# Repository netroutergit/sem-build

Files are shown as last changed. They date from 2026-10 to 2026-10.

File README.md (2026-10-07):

# Homebuilt scanning electron microscope

A hobby project to design and build a working scanning electron microscope
(SEM) from scratch: vacuum system, electron gun, magnetic lenses, scan
electronics and imaging software.

This site is the friendly overview: what it is, how far along it is, a 3D
model to look at, and photos of the parts as they get made. The detailed
engineering notes live in a separate private repo.

Site: https://netroutergit.github.io/sem-build/

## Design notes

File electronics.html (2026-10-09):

Homebuilt SEM

# Electronics

How the electronics are split up, what talks to what, and the one circuit that is allowed to switch on the high voltage. Nothing on this page has been built yet.

This page is a snapshot of the current design, not a history. The design will change many times before a board is ordered. When it does, the diagrams here are replaced and the reasons rewritten. Last revised October 2026.

## Three layers

Everything electronic in the instrument sits in one of three layers, chosen by how fast it has to react.

- The scan engine, an FPGA. An FPGA is a chip whose logic is wired up by the designer rather than fixed at the factory, so it does many things at once with exact timing. It steps the beam across the sample and samples the detector once per pixel, a million times a second, and streams the frame to the PC.
- The machine controller, a microcontroller. Everything slow: pumping down, reading the gauge, setting lens currents, lighting the status display. Ordinary firmware.
- The interlock chain, relays only. No firmware at all. It is the only thing that can permit the high voltage and the filament. The FPGA and the microcontroller can ask for high voltage off at any time, but neither can force it on.

## The boxes and the cables

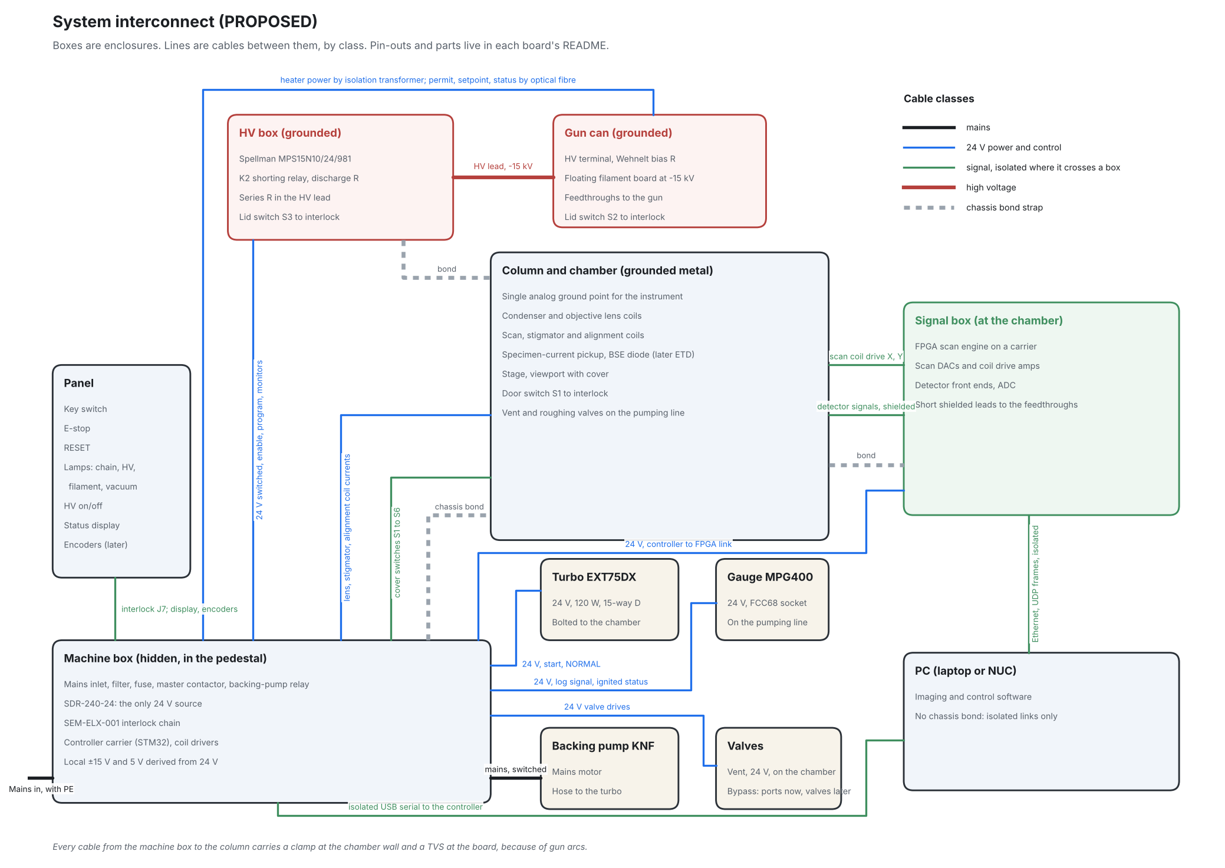
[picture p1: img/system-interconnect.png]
System interconnect diagram: a hidden machine box in the pedestal, a front panel, a grounded high-voltage box, a grounded gun can, the column and chamber, a signal box at the chamber, and the PC, wi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


Boxes are enclosures. Lines are cables, coloured by what they carry: mains, 24 volt power and control, isolated signals, high voltage, and chassis bonding straps. Pin-outs are deliberately left off.

- Machine box, hidden in the pedestal. Mains comes in through a filter and a master contactor. One industrial 24 volt supply feeds everything: turbo, gauge, valves, relays and the high-voltage module. Every other rail is made locally on the board that needs it. The interlock chain and the machine controller live here.
- Panel. A key switch, an emergency stop, a reset button, four lamps and a status display. The lamps are driven by relay contacts, not by software, so they tell the truth even if the controller is dead.
- High-voltage box and gun can. Both grounded metal. The 15 kV supply, its series resistor and the shorting relay are in the box. The gun's terminal and its floating filament supply are in the can on top of the column. Each has a lid switch in the interlock chain, because the air side of the gun is the one place 15 kV exists outside the vacuum.
- Column and chamber. Grounded metal and the single analog ground point of the instrument. The lens coils, scan coils and detectors are here, so the signal box sits right beside it with short shielded leads to the feedthroughs.
- Signal box, at the chamber. The FPGA on a carrier board, the scan drivers and the detector front ends. Fast, small signals stay close to where they are made.
- PC. No ground connection to the instrument at all. The FPGA streams frames over Ethernet, which is isolated by the transformers in every Ethernet port. The controller talks over a USB serial link through an isolator. Two cables, both floating, so a gun arc cannot find a path through the computer.

Every cable from the machine box to the column carries a clamp at the chamber wall and a protection device at the board, because an arc in the gun throws a fast pulse into anything connected to it.

## The interlock chain

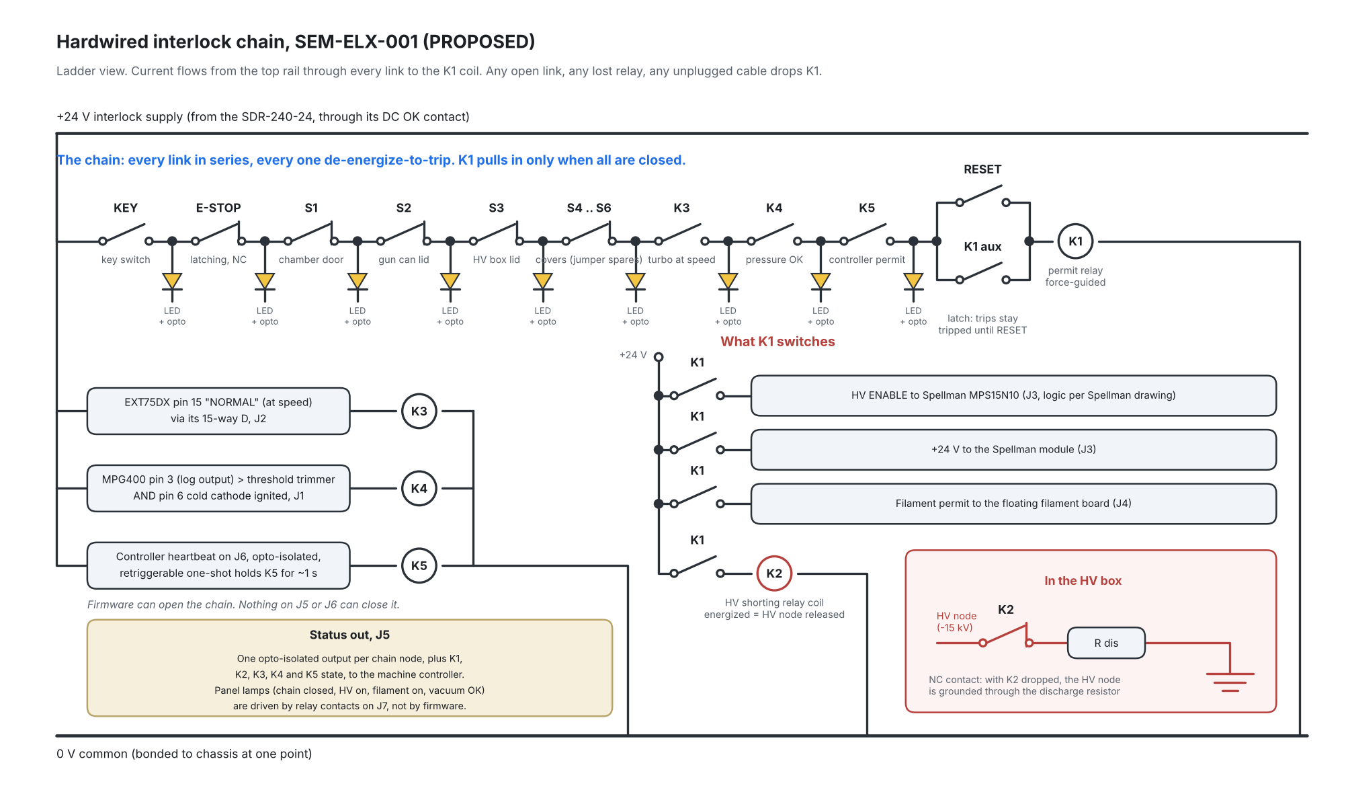
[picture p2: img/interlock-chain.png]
Ladder diagram of the interlock chain: key switch, emergency stop, cover switches, turbo-at-speed, pressure-OK and controller-permit contacts in series feeding the permit relay, with a latching rese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


Read it left to right along the top rail. Current has to pass through every switch and relay contact in series to reach the coil of the permit relay. Anything open, dropped or unplugged and the permit is gone.

- Everything is de-energize-to-trip. An open door, a dropped relay, an unplugged cable or a dead supply all look the same: the chain opens and high voltage goes off. There is no state in which a fault leaves the gun live.
- The links. A key switch. The emergency stop. A safety switch on the chamber door, the gun can lid, the high-voltage box lid and any further cover. A relay that only closes when the turbo reports it is at full speed. A relay that only closes when the gauge reads below the threshold and its cold cathode has actually lit, so an unlit gauge can never pass as vacuum. And a relay held in by the controller.
- The controller's permit is a heartbeat, not a level. The controller must toggle a line a few times a second. A one-shot keeps the relay in only while the toggling continues, so a crashed controller, a stuck pin or a pulled cable drops the high voltage within about a second. Nothing the controller can do closes any other link.
- It latches. After any trip the chain stays open until someone presses reset with every link closed. A door that closes again does not bring the gun back by itself.
- What the permit relay switches. The enable line and the 24 volt feed to the high-voltage module, so the module is unpowered when the chain is open regardless of the enable pin. The permit to the filament supply. And the coil of a shorting relay in the high-voltage box, whose normally closed contact grounds the high-voltage node through a discharge resistor whenever the chain is open or the relay loses power.
- Status can only go out. The controller gets an opto-isolated copy of every node for logging and the display, and the panel lamps are relay contacts. Neither path can close the chain.

The permit relay is a force-guided safety relay, the kind whose contacts are mechanically linked so that a welded contact shows up on the auxiliary contact instead of silently holding the gun live. The acceptance test for this board is simple: every input, opened in turn, must take the measured high voltage below 50 volts within one second.

## The boards

Six designs, about ten boards once the replicated ones are counted. One board outline and one connector family for all of them. The FPGA and microcontroller are bought modules on custom carriers rather than laid out from scratch.

Board | What it does
Interlock chain | The relay logic above. No firmware. The first board to be drawn.
Controller carrier | The microcontroller, its power, and the connectors to the gauge, turbo, valves and panel.
Scan and acquisition | Digital-to-analog converters for the scan coils, the detector analog-to-digital converter, and the FPGA carrier.
Coil driver, replicated | A precision current source. One per lens, stigmator and alignment coil, because a lens current that wanders by a part in ten thousand moves the focus.
Floating filament supply | Heats the filament while sitting at 15 kV below ground. See below.
Detector front end, replicated | A low-noise amplifier for the specimen current and the backscatter diode, later the photomultiplier electronics.

## Decisions, and the reasons behind them

- One 24 volt rail, everything else local. One supply to buy, one thing to fuse, and every board makes its own clean analog rails from it where they are used. There is no 12 volt rail because nothing needs one.
- Heating the filament across 15 kV with a transformer and light. The filament sits at the gun voltage, so its power has to cross a 15 kV barrier. The plan is a hand-wound transformer on a grounded ferrite ring: a 24 volt primary driven at high frequency, and a secondary of a few loose turns of 30 kV silicone wire whose insulation is the whole barrier. On the floating side a rectifier, a current regulator and a small microcontroller. The permit and setpoint come in over one plastic optical fibre and status goes back over another. No light, no filament. An earlier idea, a battery floating at gun voltage, was dropped: nothing to charge, nothing to run flat.
- Ethernet for the pictures, isolated serial for the controller. A frame is a megabyte and comes once a second, so Ethernet is the natural fit, and its port transformers give isolation for free. The controller has little to say and gets a slower link through a USB isolator. Both leave the PC ungrounded to the instrument.
- Relays for safety, not firmware. Firmware can have bugs, hang, or be mid-update. A relay chain fails only one way, open, and can be tested with a switch and a meter.
- Panel lamps from relay contacts. The lamp that says the chain is closed is wired to the chain. It cannot disagree with reality.
- Bought modules on custom carriers. Laying out a modern FPGA with its memory and power is a project in itself. A commercial module does that; the carrier only has to route its pins to the instrument's connectors.

The detailed engineering notes live in a separate private repository. This site is the friendly overview. Source for the site: github.com/netroutergit/sem-build.

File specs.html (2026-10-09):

Homebuilt SEM

# Headline numbers

These are design targets. Nothing has been measured yet; the first measurement will be the vacuum test. Each row says what the number means in plain words.

## The beam

What | Target | What it means
Beam energy | 5 to 15 kV | How hard the electrons are flung at the sample. Set by the voltage on the gun. Higher gives a finer spot but more X-rays, so 15 kV is the ceiling.
Electron source | Tungsten hairpin | A V-shaped tungsten wire heated to about 2,700 K. Electrons boil off the tip. The same kind of filament commercial SEMs used for decades, bought as a consumable.
Lenses | Two, magnetic | A condenser lens that does the first shrink of the beam, and an objective lens that forms the final focus on the sample. Both are coils in steel shells, made on the lathe.
Spot size, predicted | 130 to 255 nm | How small the beam can be focused with both lenses on. That is the detail the microscope can resolve. A human hair is about 70,000 nm across.
Spot size, first image | about 3 µm | With only the objective lens running. Coarser, but it carries over a hundred times more current, which makes the first image easy to get.
Beam current | 0.5 nA to over 100 nA | How many electrons per second land on the sample. A smaller spot always carries less current, so the best resolution comes with the weakest signal.

## The hardware

What | Target | What it means
Vacuum | 10⁻⁵ Torr | About one hundred-millionth of atmospheric pressure. Needed so electrons do not scatter off air, the filament does not burn out, and the high voltage does not arc. The pump bought should hold the chamber near 4 × 10⁻⁶ Torr, a little better than needed.
Turbo pump | Edwards EXT75DX, 61 L/s | A turbomolecular pump, a stack of blades spinning at tens of thousands of rpm, does the hard work. Bought used, drive electronics built in, 95 mm inlet flange. See milestone 2.
Backing pump | KNF dry diaphragm | Takes the chamber from atmosphere to about half a Torr and carries away the turbo's exhaust. No oil anywhere, so nothing can creep back toward the column.
Gauge | Inficon MPG400 | One gauge that reads from atmosphere down to a hundred-millionth of a Torr, by combining two sensors in one body and switching between them on its own.
Column height | about 450 mm | From the sample up to the top of the gun. The chamber and the pump hang below that.
Objective lens | 114 mm across, 95 mm tall | Three turned pieces of low-carbon steel around a 1,000-turn coil. The underside is tapered to a 24 mm nose so an X-ray detector can see the sample later.
Condenser lens | 110 mm across, 59 mm tall | Same construction, 1,500-turn coil. Both lenses fit a 12-inch lathe.
Sample chamber | 150 mm cube inside | Machined from aluminium with bolt-on, O-ring-sealed plates, so no welding and no leak detector needed.
Samples | up to about 25 mm | Sit on the standard half-inch pin stubs every SEM uses. Electrically conductive samples first, such as metal parts and meshes.
Scan | 1024 × 1024 pixels | At 1 microsecond per pixel, a full frame takes about a second. An FPGA steps the beam and samples the detector so every value lands in exactly the pixel it belongs to.

## The goals, in order

Goal | Passes when
First image | A copper mesh of known spacing is recognisable, and its measured spacing is within 10% of the real thing.
Real detector | A backscatter diode or a secondary-electron detector gives a cleaner picture than the simplest signal, and a two-metal sample shows which metal is which.
Sub-micron resolution | Detail under 1 µm resolved with both lenses running. Stretch goal: under 200 nm.
Automation | One-command pump-down, a motorised stage, autofocus, and stitched mosaics of many frames.
Element identification | An X-ray detector (EDS) that tells copper from aluminium by the energy of the X-rays each gives off. Budgeted and planned separately, but the chamber is designed so it fits.

The detailed engineering notes live in a separate private repository. This site is the friendly overview. Source for the site: github.com/netroutergit/sem-build.

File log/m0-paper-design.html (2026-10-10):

Homebuilt SEM

# Milestone 0: paper design

October 2026. Before buying anything, work the whole instrument through on paper so that a fundamental problem shows up while it is still free to fix.

## Why now

A home-built electron microscope has been an idea for years, and a slow gathering: metal stock, power supplies, interlock parts and gun sketches collected as they came along, none of it to a plan. What changed is not the physics. The skills the build needs, lathe and mill work, PCB design and software, had finally all come together in one workshop, so no part of it had to be farmed out or faked. And documentation, which would otherwise never have happened, became cheap: AI tools turn a session's working notes into a design record the same day, so every calculation, decision and surprise is written down while it is fresh. That record is what makes a milestone-gated plan possible, and it is why this milestone exists before a single part has been cut.

## What got done

- The optics close on paper. A simple model of the two-lens column predicts a spot of 130 to 255 nm with both lenses running, and about 3 µm with the objective alone. The sub-micron goal is realistic.
- The lenses were simulated and then drawn. A free finite-element program (FEMM) that calculates magnetic fields checked the steel shapes. It agrees with the simple model to within about 5%, and the steel stays comfortably below the point where it stops carrying more field. Both lenses now exist as 3D parts, three turned pieces each, and they fit the lathe. See the 3D model.
- The gun insulator was shaped by calculation. The same kind of field calculation, this time electric, found a shape for the high-voltage parts that stays within safe limits at 15 kV. The insulator will be machined from PEEK, a plastic that is easy to turn and holds off high voltage well.
- The whole column was laid out. Every dimension the physics depends on lives in one shared file, which the optics model, the field checks, the cross-section sketch and the CAD scripts all read. Change a number once and everything regenerates.
- The regulatory question was answered. Texas exempts electron microscopes from radiation-machine registration by name. The duty to keep X-rays below the limit stays, and the design treats that limit as a hard one.

## Surprises

- The gun could not be pumped. The first layout had the gun's vacuum pulled through the narrow beam tube. Working the numbers showed the tube passes far too little gas, and almost none once the tiny final aperture is fitted. The gun now gets its own hose to the chamber. Caught on paper before any hardware existed.
- The first gun shape would have arced. Two places broke the electric-field limit. The obvious fix, a rounded dome resting on the insulator, made it worse. A fat 25 mm stem standing clear of the surface fixed both.
- A flat lens blocks the X-ray view. The objective lens sits only 10 mm above the sample, and a future X-ray detector has to look at the sample from about 35 degrees. A flat-bottomed lens was in the way, so the underside now tapers to a 24 mm nose, as it does on commercial instruments.
- The condenser has a floor. With its chosen gap and bore it cannot focus shorter than about 4.4 mm, and that is what sets the resolution limit near 130 to 180 nm. Going further would need a smaller bore, a longer column or a third lens.

## Next

Measure the stray magnetic field in the workshop where the instrument will stand, since mains hum can push the beam around. Then the first real purchase: a used turbo pump, a backing pump and a gauge, proven on a test volume before anything custom is machined. That purchase has since been made; see milestone 2.

The detailed engineering notes live in a separate private repository. This site is the friendly overview. Source for the site: github.com/netroutergit/sem-build.

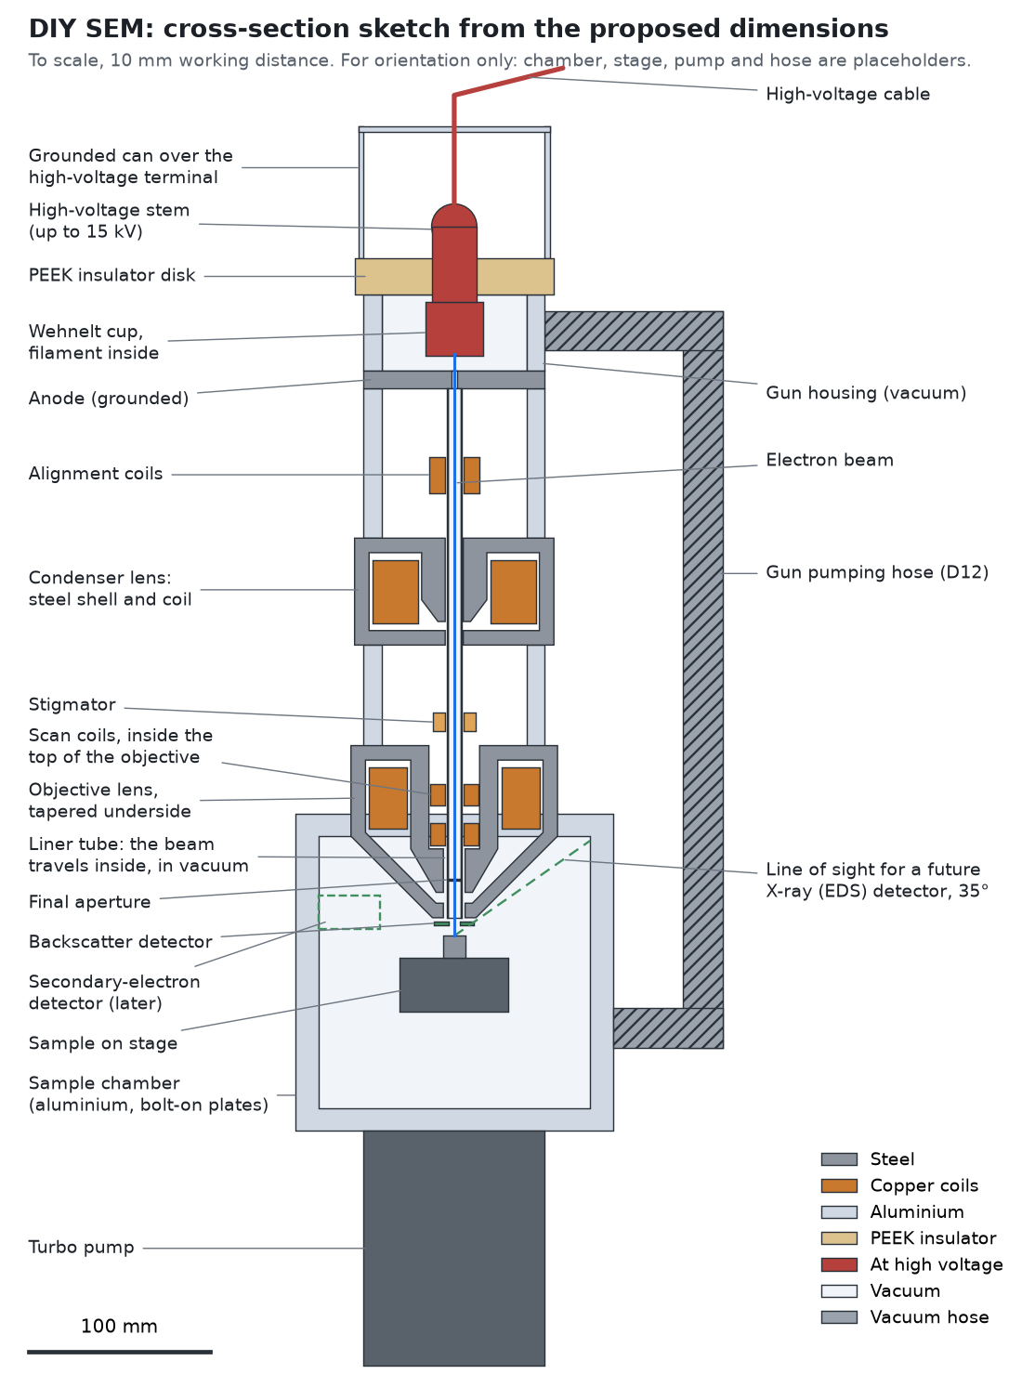
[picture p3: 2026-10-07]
img/column-cross-section.png

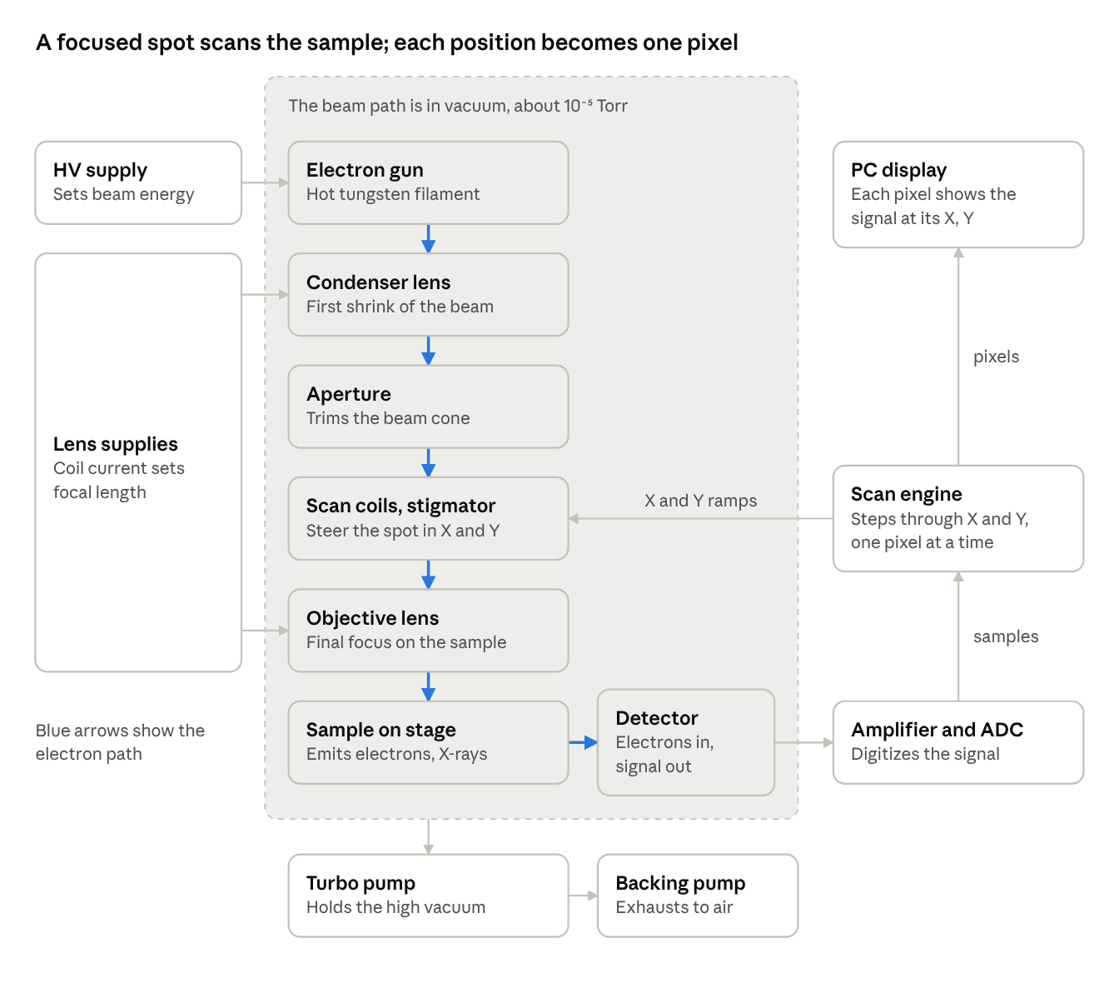
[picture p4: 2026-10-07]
img/sem-block-diagram.png

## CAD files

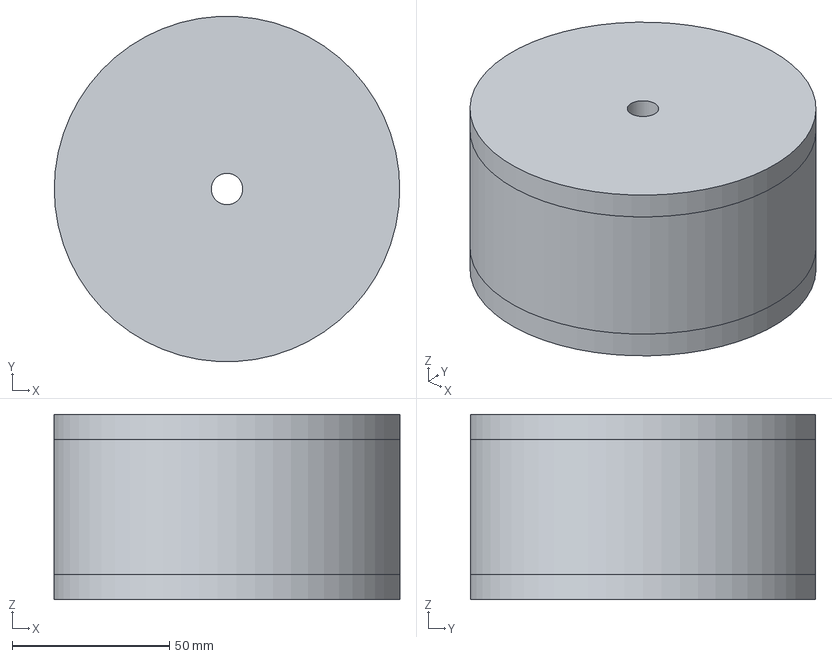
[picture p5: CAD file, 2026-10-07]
models/SEM-LNS-010-P1_condenser-lens-assembly.step
110.0 x 109.8 x 59.0 mm
condenser-upper-pole
condenser-shell-ring
condenser-lower-pole
condenser-coil

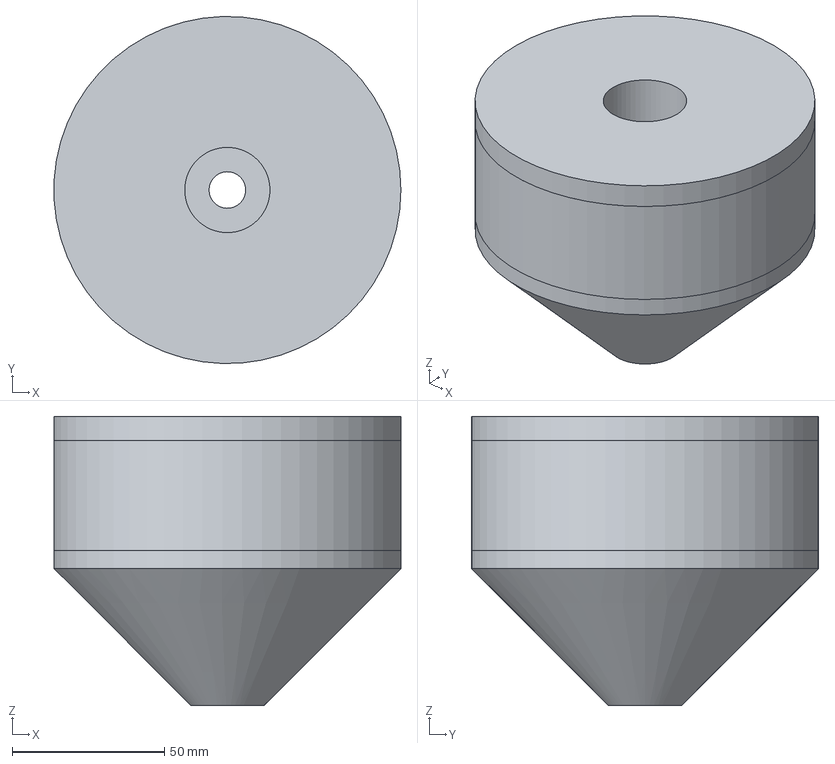
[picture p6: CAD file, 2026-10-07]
models/SEM-LNS-000-P1_objective-lens-assembly.step
113.9 x 114.0 x 95.0 mm
objective-upper-pole
objective-shell-ring
objective-lower-pole
objective-coil

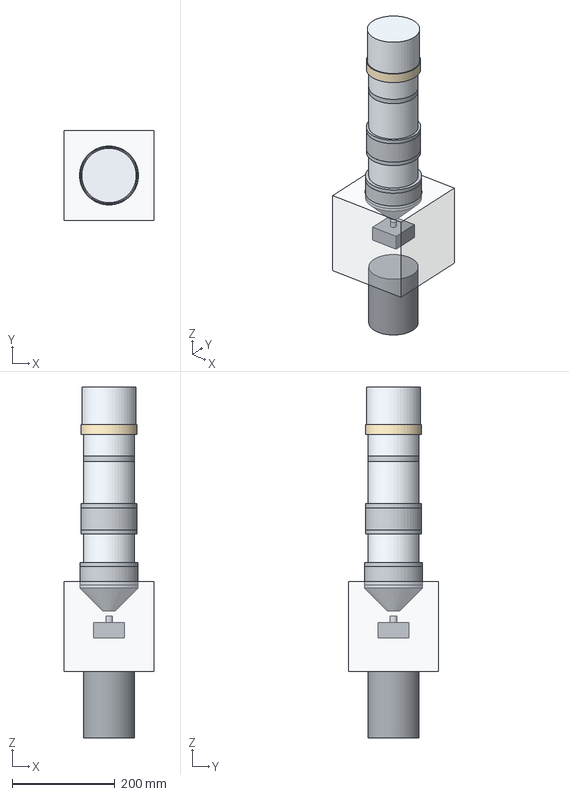
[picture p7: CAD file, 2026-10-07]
models/SEM-LAYOUT-P1.step
175.0 x 175.0 x 684.5 mm
objective-upper-pole
objective-shell-ring
objective-lower-pole
objective-coil
condenser-upper-pole
condenser-shell-ring
condenser-lower-pole
condenser-coil
liner-tube
spacer-objective-to-condenser
spacer-condenser-to-gun
scan-coil-lower
scan-coil-upper
stigmator
gun-alignment-coils
anode-plate
gun-housing
wehnelt
high-voltage-stem
peek-insulator
grounded-can
chamber-placeholder
sample-stub
stage-placeholder
turbo-pump-placeholder

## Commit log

2026-10-07 Add intake tools: clean_photo.py and check_clean.py
    clean_photo.py re-encodes a photo from pixels only (EXIF, GPS, serial,
    thumbnail, ICC, XMP and comments all dropped), applies the orientation
    flag first, resizes to 1600 px wide, writes a progressive JPEG, and
    verifies nothing survived. Refuses to write into intake/.
    check_clean.py walks the repo (skipping .git and intake/) and exits 1 if
    any image carries EXIF, XMP or a comment block, if a raw/HEIC/original
    photo is present, or if any text file holds an email address, phone
    number or secret-looking string. Dollar amounts are warnings only.
    --staged scans only staged files so it can run as a pre-commit hook.
    Tested against a synthetic pho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
2026-10-07 First version of the site: overview, specs, 3D model, milestone 0
    Four plain HTML pages and one stylesheet, system fonts, phone-friendly.
    The 3D page uses Google model-viewer from a CDN and opens in section
    view (the model cut in half) with a toggle to the whole model, and a
    model picker for the whole instrument, objective lens and condenser lens.
    Models: the three revision-P1 STEP assemblies from the private repo,
    copied as-is for download, plus GLB versions for the viewer made with
    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
    [SEM-LAYOUT-P1.step, SEM-LNS-000-P1_objective-lens-assembly.step, SEM-LNS-010-P1_condenser-lens-assembly.step]
2026-10-09 Electronics page: boxes and cables, interlock chain, planned boards, reasons
2026-10-13 Pick up the instrument name: Gray SEM
    The private design record named the instrument family Gray and this
    instrument the Gray SEM, serial 1. The site title, page titles, brand
    link and descriptions now say Gray SEM, and the overview gets a short
    section on the name. STEP files are renamed to the GRAY-SEM prefix to
    match the source; their contents are unchanged. The two electronics
    diagrams are refreshed from the source, which now labels the interlock
    board GRAY-ELX-001, rewritten from pixels as before.
2026-10-16 Milestone 2: pumps and gauge arrived, turbo hand checks passed, test stack assembled, first photos; electronics page: interlock board drawn and rendered, vacuum interface board added
